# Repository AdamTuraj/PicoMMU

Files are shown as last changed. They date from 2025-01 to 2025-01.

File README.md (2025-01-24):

# PicoMMU

PicoMMU is a PCB designed to control a stepper motor and servo for a multi-material unit. It is compatible with Klipper firmware.
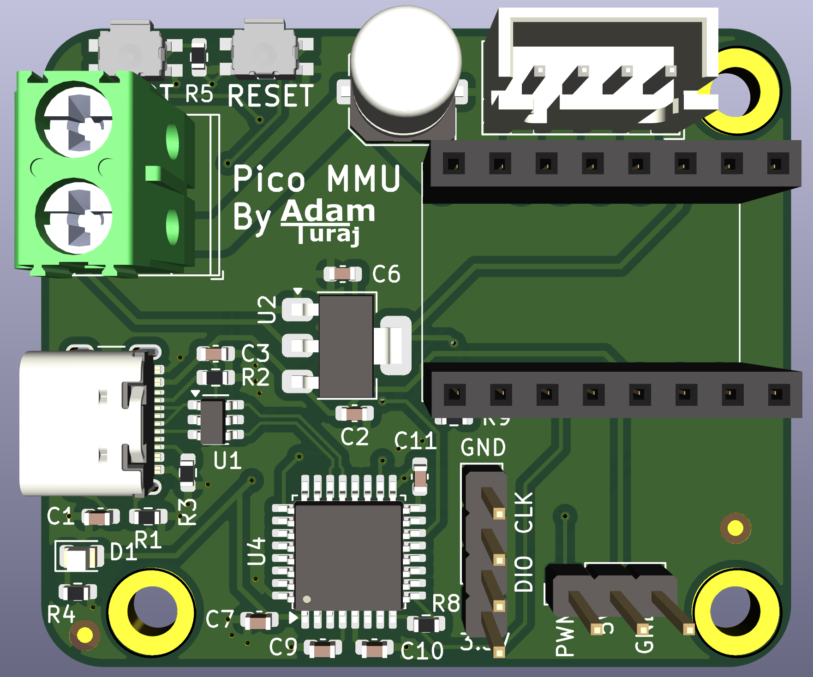
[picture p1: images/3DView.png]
A 3D render of the PCB


## Requirements

- A USB C cable to connect to your RPI / Printer
- A 12-24V power supply
- A TMC2209 (BTT Recommended)
- A stepper motor crimped with a 4 pin JST XH B4

## Flashing Klipper

1. Follow [this Klipper guide](https://www.klipper3d.org/Installation.html) on how to build the firmware. The first image shows the configuration settings and the second shows the "Optional Features" section.
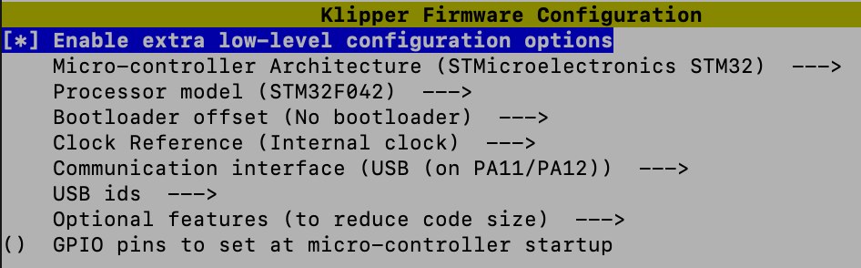
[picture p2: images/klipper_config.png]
The configuration for Klipper. Select STMF042 as the chip, change "Bootloader Offset" to "No Bootloader" and under extra low-level configuration options change "Clock Reference" to "Internal Clock".
  
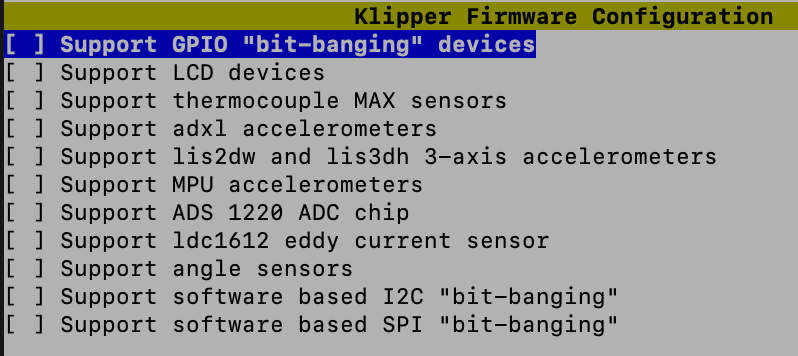
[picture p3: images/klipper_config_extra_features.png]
The optional features section, should be all off as there is not enough flash memory to support all features.
  
2. Once the firmware is build, put the chip into DFU mode by clicking the reset button while holding the boot button.
3. Run lsusb and take not of the numbers in this format: xxxx:xxxx.
4. Now use the following command to flash the firmware (replacing xxxx:xxxx with your MCU's ID): `make flash FLASH_DEVICE=xxxx:xxxx`.
5. Unplug and replug in the USB cord and your MCU should pop up in `ls /dev/serial/by-id/*`.

## License

This project is licensed under the MIT License.

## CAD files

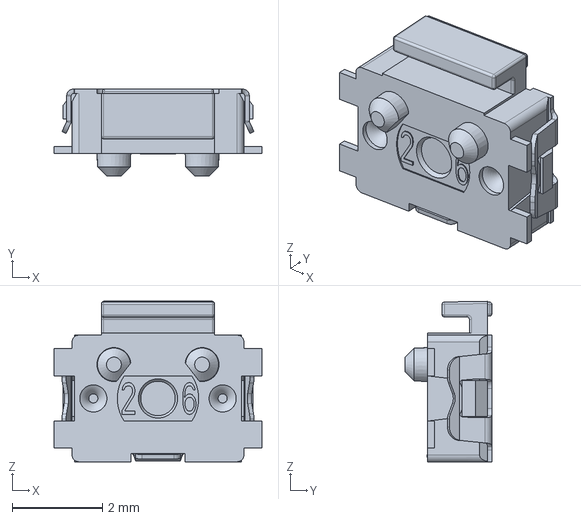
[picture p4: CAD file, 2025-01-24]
Kicad/STEP/KMS233GPLFG.stp
4.60 x 1.92 x 3.55 mm

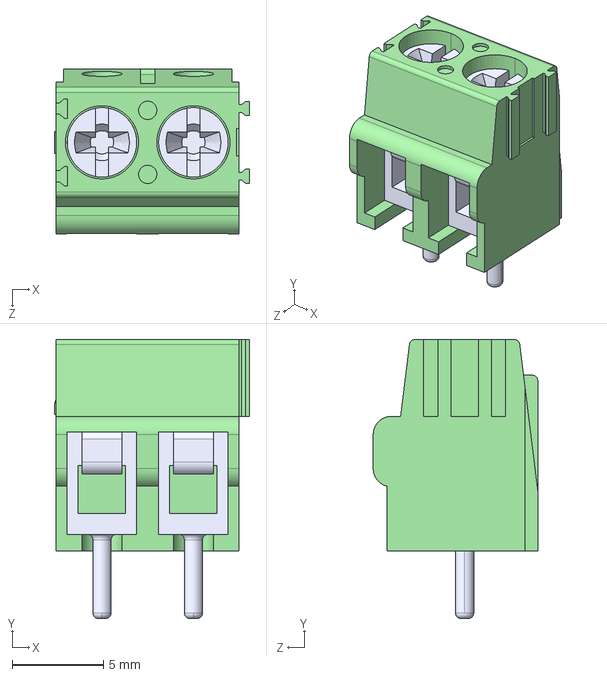
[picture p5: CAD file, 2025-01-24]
Kicad/STEP/Screw_Terminal.step
10.7 x 15.2 x 9.00 mm

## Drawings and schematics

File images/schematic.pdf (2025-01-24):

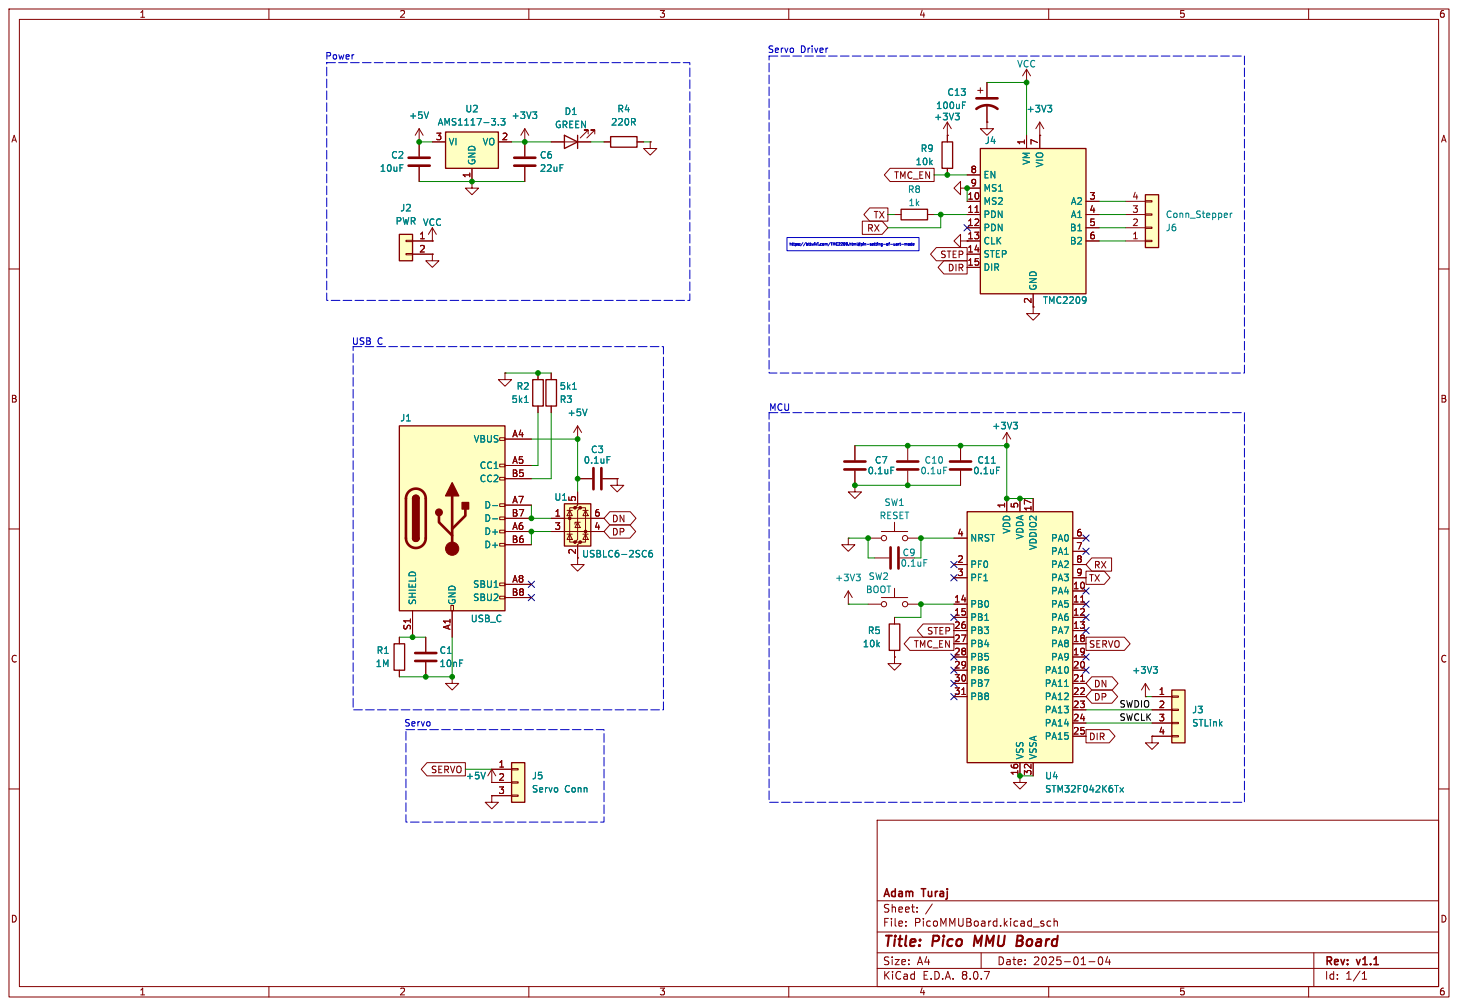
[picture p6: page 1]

Id: 1/1 Title: Pico MMU Board

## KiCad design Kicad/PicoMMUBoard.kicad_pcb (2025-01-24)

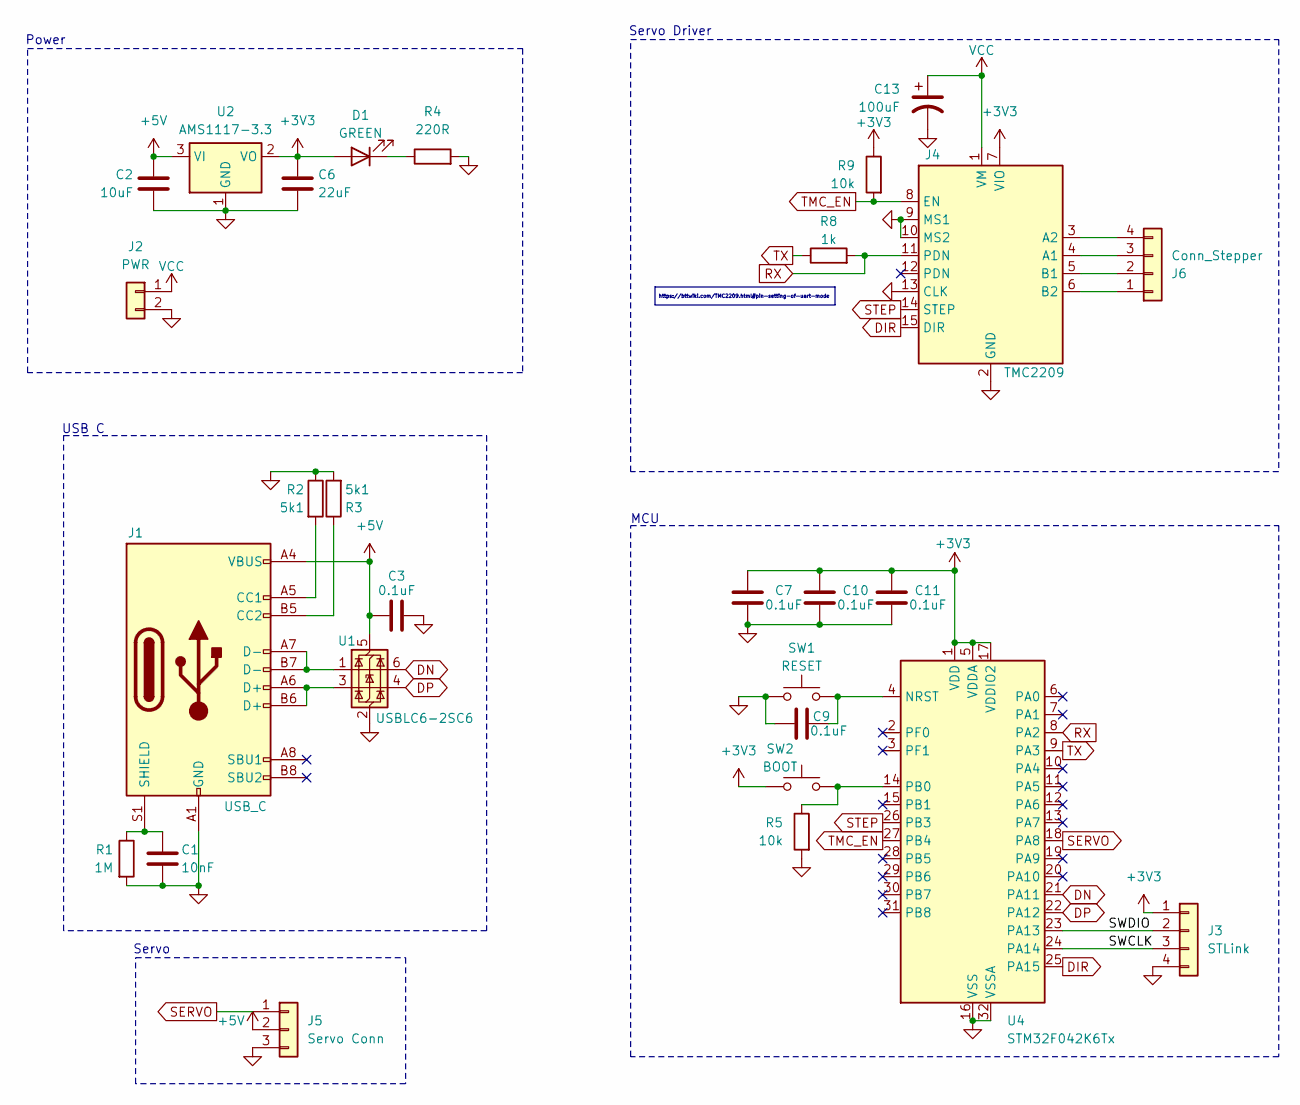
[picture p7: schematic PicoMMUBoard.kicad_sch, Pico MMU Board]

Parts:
C1: 10nF; C_0603_1608Metric
C2: 10uF; C_0603_1608Metric
C3, C7, C9, C10, C11: 0.1uF; C_0603_1608Metric
C6: 22uF; C_0603_1608Metric
C13: 100uF; C_Elec_6.3x7.7; LCSC C3151829
D1: GREEN; LED_0805_2012Metric; LCSC C2297
J1: USB_C; USB_C_Receptacle_GCT_USB4105-xx-A_16P_TopMnt_Horizontal; LCSC C165948
J2: PWR; TerminalBlock_MetzConnect_Type073_RT02602HBLU_1x02_P5.08mm_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; LCSC C8465
J3: STLink; PinHeader_1x04_P2.54mm_Vertical
J4: TMC2209
J5: Servo Conn; PinHeader_1x03_P2.54mm_Vertical; LCSC C144394
J6: Conn_Stepper; JST_XH_B4B-XH-A_1x04_P2.50mm_Vertical; LCSC C594232
R1: 1M; R_0603_1608Metric
R2, R3: 5k1; R_0603_1608Metric
R4: 220R; R_0603_1608Metric
R5, R9: 10k; R_0603_1608Metric
R8: 1k; R_0603_1608Metric
SW1: RESET; SW4_KMS-P; LCSC C221703
SW2: BOOT; SW4_KMS-P; LCSC C221703
U1: USBLC6-2SC6; SOT-23-6; LCSC C2827654
U2: AMS1117-3.3; SOT-223-3_TabPin2; LCSC C6186
U4: STM32F042K6Tx; LQFP-32_7x7mm_P0.8mm; LCSC C1337340

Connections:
+3V3: C6.1, C7.2, C10.2, C11.2, D1.2 (A), J3.1, J4.7 (VIO), R9.1, SW2.1, U2.2 (VO), U4.1 (VDD), U4.5 (VDDA), U4.17 (VDDIO2)
+5V: C2.1, C3.1, J1.A4 (VBUS), J1.A9 (VBUS), J1.B4 (VBUS), J1.B9 (VBUS), J5.2, U1.5 (VBUS), U2.3 (VI)
/SWCLK: J3.3, U4.24 (PA14)
/SWDIO: J3.2, U4.23 (PA13)
DIR: J4.15 (DIR), U4.25 (PA15)
DN: U1.6 (I/O1), U4.21 (PA11)
DP: U1.4 (I/O2), U4.22 (PA12)
GND: C1.2, C2.2, C3.2, C6.2, C7.1, C9.2, C10.1, C11.1, C13.2, J1.A1 (GND), J1.A12 (GND), J1.B1 (GND), J1.B12 (GND), J2.2, J3.4, J4.2 (GND), J4.9 (MS1), J4.10 (MS2), J4.13 (CLK), J5.3, R1.2, R2.1, R3.2, R4.2, R5.2, SW1.1, U1.2 (GND), U2.1 (GND), U4.16 (VSS), U4.32 (VSSA)
unnamed: D1.1 (K), R4.1
unnamed: J1.A5 (CC1), R2.2
unnamed: J1.B5 (CC2), R3.1
unnamed: J1.A6 (D+), J1.B6 (D+), U1.3 (I/O2)
unnamed: J1.A7 (D-), J1.B7 (D-), U1.1 (I/O1)
unnamed: C1.1, J1.S1 (SHIELD), R1.1
unnamed: J4.4 (A1), J6.3
unnamed: J4.3 (A2), J6.4
unnamed: J4.5 (B1), J6.2
unnamed: J4.6 (B2), J6.1
unnamed: C9.1, SW1.2, U4.4 (NRST)
unnamed: R5.1, SW2.2, U4.14 (PB0)
RX: J4.11 (PDN), R8.2, U4.8 (PA2)
SERVO: J5.1, U4.18 (PA8)
STEP: J4.14 (STEP), U4.26 (PB3)
TMC_EN: J4.8 (EN), R9.2, U4.27 (PB4)
TX: R8.1, U4.9 (PA3)
VCC: C13.1, J2.1, J4.1 (VM)

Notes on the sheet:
https://bttwiki.com/TMC2209.html#pin-setting-of-uart-mode
Power
Servo
MCU
USB C
Servo Driver

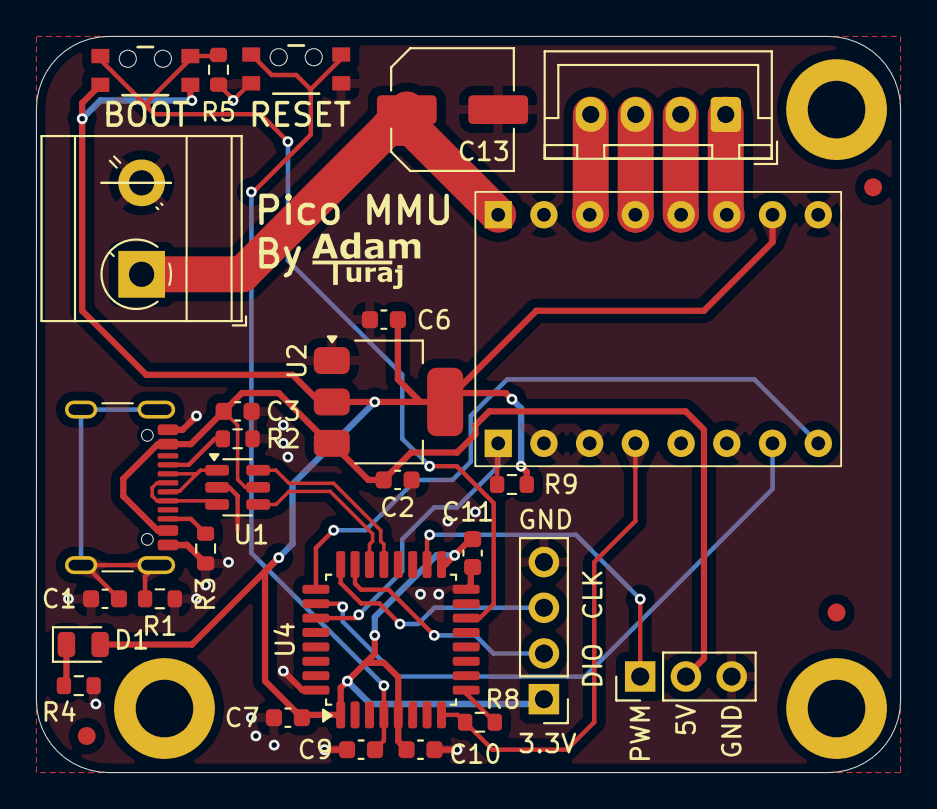
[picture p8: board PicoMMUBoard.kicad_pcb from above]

Board: 2 copper layers, 48.0 x 40.9 mm, 28 parts (0 on the bottom side), 26 nets.
